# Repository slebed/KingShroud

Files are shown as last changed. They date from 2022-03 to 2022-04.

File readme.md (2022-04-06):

---
title: S. Lebed's RAT RIG Mods Page
---

> Created by: [Stephen Lebed](https://github.com/slebed)

## Description
Welcome to my Rat Rig Mods page.

## My Setup
I've designed all these mod around my Rat Rig V-Core3.  Its a custom size at 400x by 400y by 500z.  My toolhead is an EVA2.4 with a BondTech LGX, Mosquito Magnum and a CHT nozzle.

I have no plans to enclose my printer at this time and I don't even have an electronics panel.  All my electronic components are mounted on DIN rails.  I used the Rat Rig designed Y endstop block to secure the DIN rails to the 3030 extrusions allowing my to adjust the rails up or down as needed.

## My Stuff
Here are the links to my mods...   

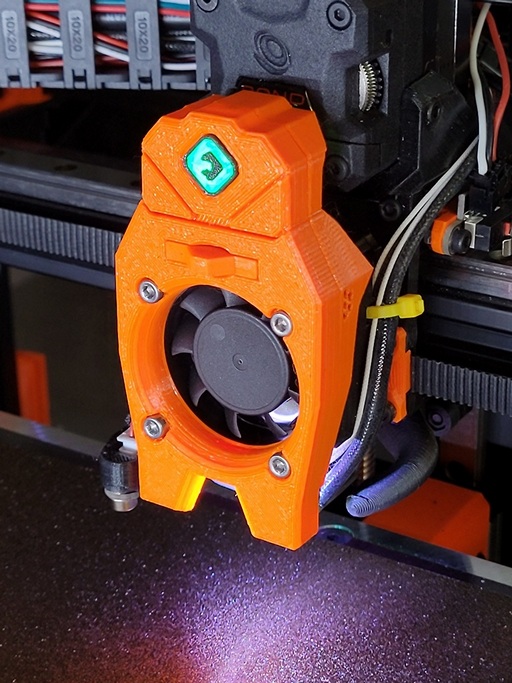
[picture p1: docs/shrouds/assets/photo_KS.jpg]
Stephen's King Shroud


[Click here for the Kings Shroud information and build instructions.](docs/shrouds/kings_shroud.md)

[Click here for my Auto Z offset information and build instructions.](docs/autoZ/autoZ.md)

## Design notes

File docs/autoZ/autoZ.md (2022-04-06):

---
title: S. Lebed's Auto Z offset Calibration
---
[Back to Index Page](../../readme.md)

> Created by: [Stephen Lebed](https://github.com/slebed)

S. Lebed's Auto Z offset Calibration

## Description
This is mod I designed for the Rat Rig V-Core3 3D Printer.  Inspired by the Voron auto Z offset calibration created by [Protoloft and can be found here.](https://github.com/protoloft/klipper_z_calibration)

#### Disclaimer
The names Voron, Stealthburner, EVA and Queen shroud are owned by their respective parties.  This design is under the same license as EVA 2.4 which is [CC BY-SA 4.0 license](https://creativecommons.org/licenses/by-sa/4.0/).

> **Warning:** This is a BETA release!  The stl files are getting updated often.  Please refer to the changelog.  These instructions may not be complete!

If you want to contact me I'm **slebed#1717** on the [Unofficial Rat Rig Discord Server](https://discord.gg/hEQhKNxN)

#### Attributions
This wouldn't have been possible without the amazing work done by the team at Rat Rig, Protoloft, Klipper and others.

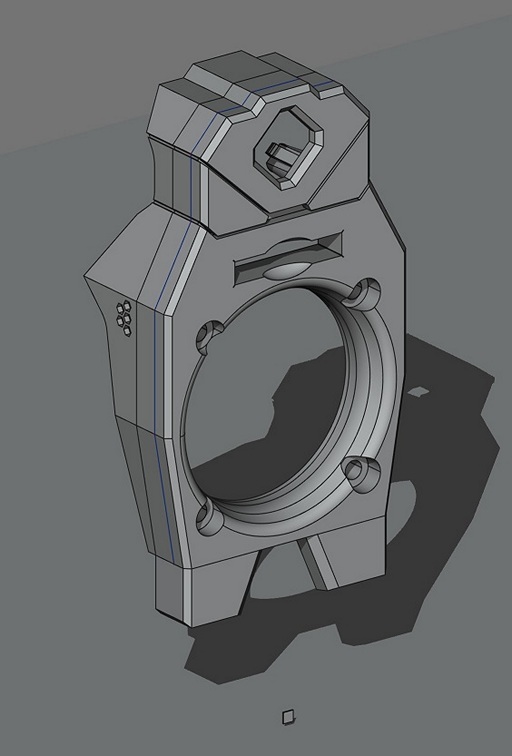
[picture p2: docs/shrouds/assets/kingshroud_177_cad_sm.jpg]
Stephen's King Shroud


## BOM

| No | Qty | Name | Printable | Notes|
| -- | --- | --- | --- |---|
| 1  | 1 | AutoZ Front Left Bedplate Endstop | [Yes](stl/KingsShroud_v179_body.stl)|
| 2  | 1 | AutoZ Rear Left Bedplate cable holder and flex plate guide | [Yes](stl/KingsShroud_v179_back.stl)||
| 3  | 1 | AutoZ Rear Right Bedplate flex plate guide | [Yes](stl/KingsShroud_v174-LogoLEDHolderLEDholder.stl)||
| 4  | 3 |Neopixel LED (ws2812)|No|I used these from [Amazon.com](https://www.amazon.com/dp/B00P2GQUYC/ref=cm_sw_em_r_mt_dp_PMNZGTJADRJEV3NSN1C2?_encoding=UTF8&psc=1) but any compatible ones should work.|
| 5  | 3 | 24awg stranded wire |No |I used this from [Amazon.ca](https://www.amazon.ca/dp/B07THYKBBK/ref=cm_sw_em_r_mt_dp_ZGJWJ1PHSKGGRQ51FVXV?_encoding=UTF8&psc=1)  |
| 6 | 2 | M2 or M2.5 x20mm Caphead screws 	 | No  ||
| 7 | 2 | M2 and M2.5 washers and nuts 	| No  ||

## Compatibility

This was designed around a stock V-Core 3 400, EVA 2.4 toolhead, and Euclid Probe

## Print preparation

Print the KingsShroud_v176.stl face down on the bed in your primary color.  Note that these parts were designed to be printed with PETG and are a tight fit.  If printing in ABS, please adjust for shrinkage.

I used SuperSlicer to print my parts using the following settings
 - 0.4 nozzle
 - 4 perimeters
 - 5 top and bottom layers
 - No supports are necessary
 - Bottom infill set to Archimedean Chords

 Wait!? What's that infill all about?  And what's going on with this...

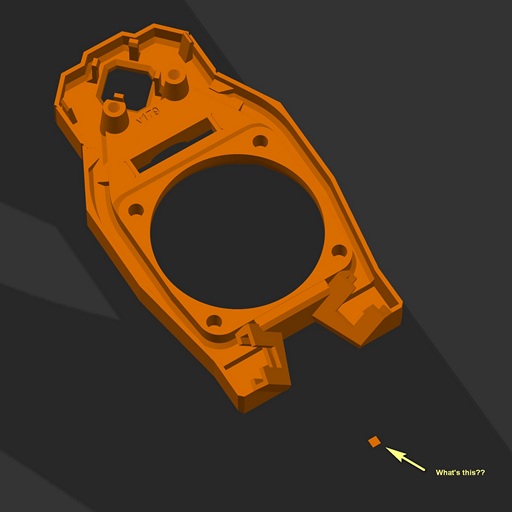
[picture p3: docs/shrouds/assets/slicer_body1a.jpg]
Stephen's King Shroud
 

Well its a small detail, but if print the body by itself and you set infill to this...

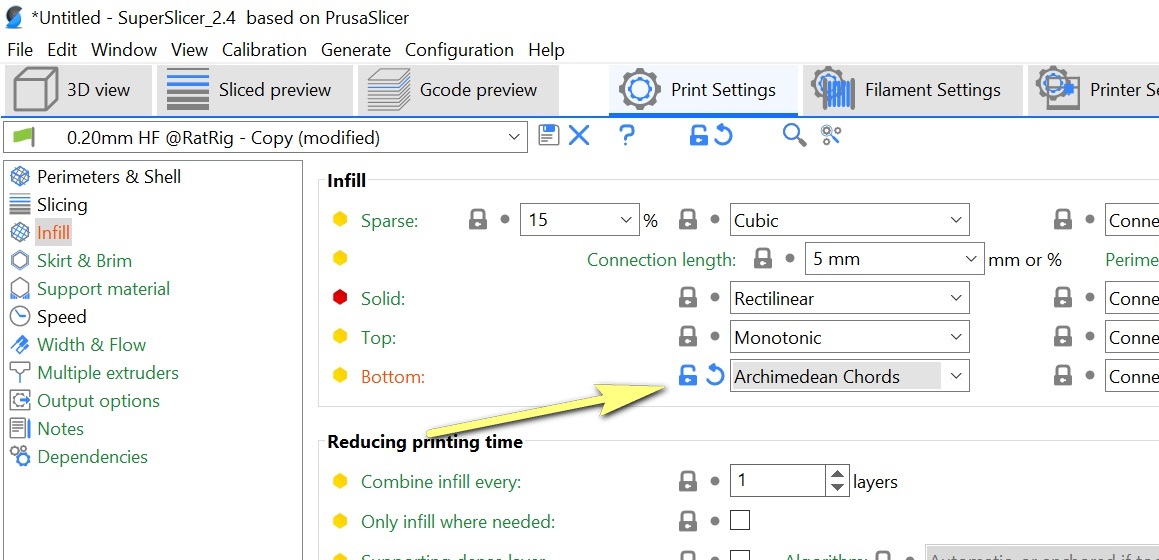
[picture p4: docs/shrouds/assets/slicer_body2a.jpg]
Stephen's King Shroud
  

Then the slicer will create this...

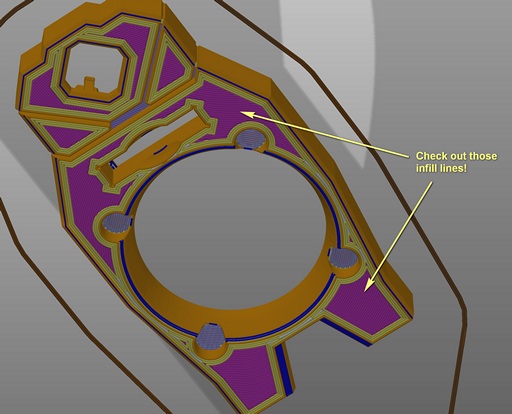
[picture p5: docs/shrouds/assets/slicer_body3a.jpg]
Stephen's King Shroud
 

 All the infill will radiate outward from the fan opening.

 Granted, its a detail that probably won't show if you print on a textured sheet or have a lot of squish, but its there.

> **Note:** The are four 'Pokey Poke' holes that will need to be drilled out prior to assembly.

Here is a image showing how the parts should be oriented in your slicer.

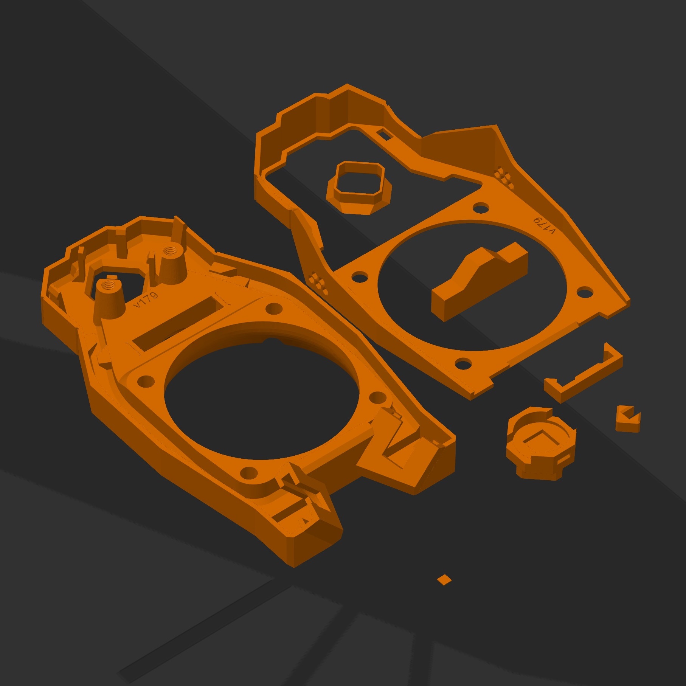
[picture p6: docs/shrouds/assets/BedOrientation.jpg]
Stephen's King Shroud
 

## Assembly instructions

#### Assembling the Logo LED Holder

Here are the printed parts for the Logo LED Holder.

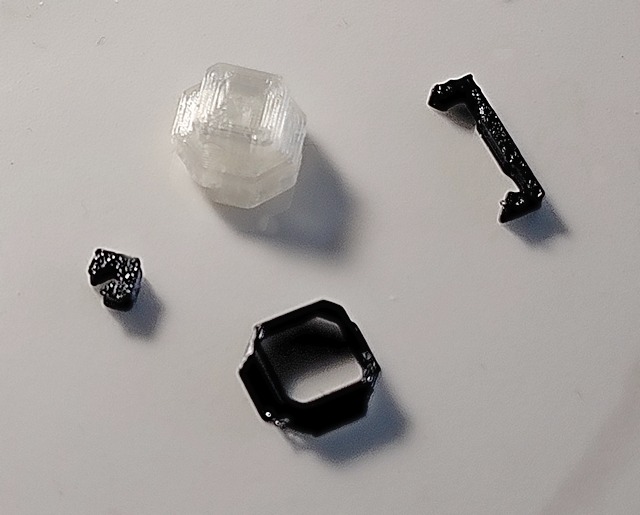
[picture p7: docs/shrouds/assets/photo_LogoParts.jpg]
Stephen's King Shroud
  

 - Press the EVA logo insert into the EVA Logo LED holder as shown in yellow below.

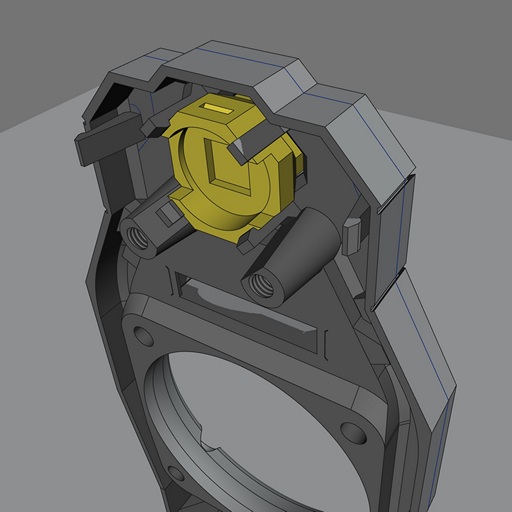
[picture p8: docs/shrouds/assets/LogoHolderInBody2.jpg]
Stephen's King Shroud
 

 - Press the EVA logo sheath onto the EVA logo LED holder as shown in yellow below.

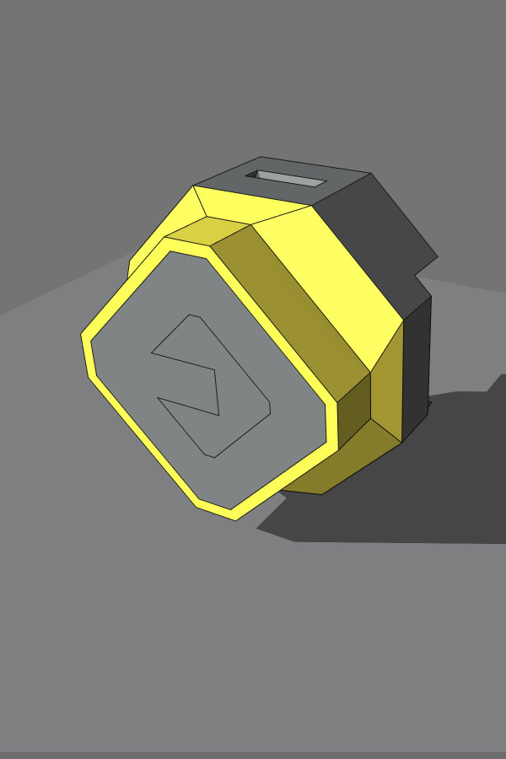
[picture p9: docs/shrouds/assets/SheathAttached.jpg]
Stephen's King Shroud
    

    Example of the assembled LogoLEDHolder

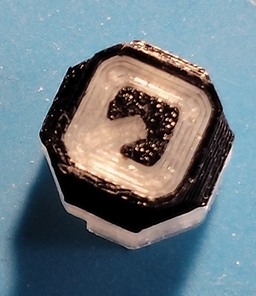
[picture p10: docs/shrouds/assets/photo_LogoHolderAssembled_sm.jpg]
Stephen's King Shroud
     

 - Press the EVA logo LED holder into the back of the King Shroud body as shown in yellow below.  The part should press fit into the opening in the body.

 > **Note:** Make sure the logo holder is oriented like the image below.  From the front the logo should be oriented like the photo above.

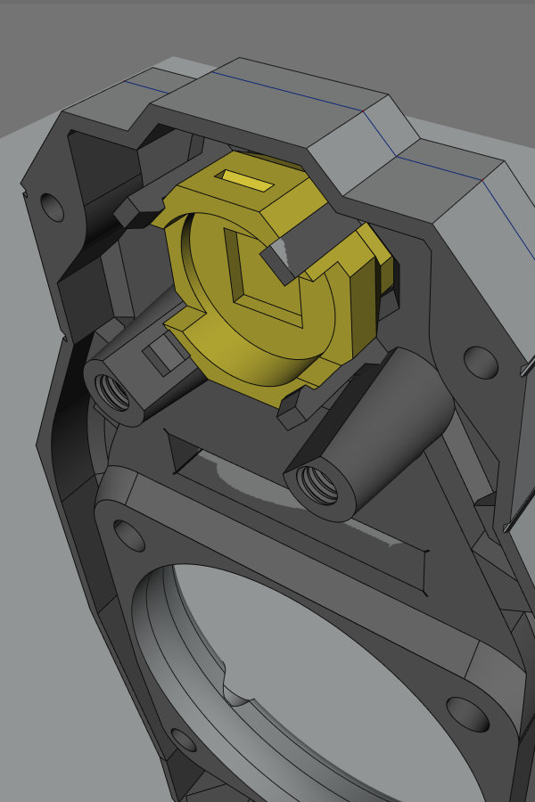
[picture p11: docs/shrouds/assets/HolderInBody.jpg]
Stephen's King Shroud
    

#### Wiring the Neopixel (ws2812) LED harness

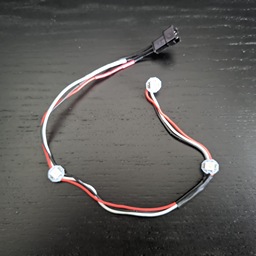
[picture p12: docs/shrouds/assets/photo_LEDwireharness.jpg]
Stephen's King Shroud
 

I used 28awg stranded wire cut to the following lengths: 3x 100mm long, 3x 60mm long, and 3x as long as you need to go from the first LED in line to a connector outside the King Shroud, at least 60mm.

- Solder the wires from the outside three pin connector to the 'IN' pins on the first LED.
- Solder the three 100mm wires from the 'OUT' of the first LED to the 'IN' of the second LED.
- Solder the three 60mm wires from the 'OUT' of the second LED so they all are laying over the three wires going 'IN'.
- Solder the other ends of the three 60mm wires to the 'IN' of the last LED.  

#### Inserting the LEDs into the King shroud

 - Starting with the last LED, insert it into the bottom right side of the King Shroud with the wires pointing out.  Slide the LED disk into the channel making sure the square housing of the LED should fits nicely into the slot.  The square LED housing should slide all the way into the channel.  A small nub will keep the LED from falling out.

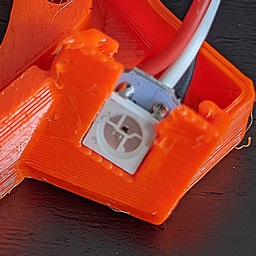
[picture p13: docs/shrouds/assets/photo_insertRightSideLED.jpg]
Stephen's King Shroud


- Insert the next LED into the left side bottom.  Make sure the LED is oriented so that all the wires are sticking out from the body.  Carefully press the LED completely into the holder for it.

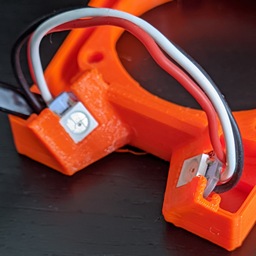
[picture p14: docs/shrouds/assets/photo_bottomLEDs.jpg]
Stephen's King Shroud


- Using a small flathead screwdriver or Allen wrench, careful push the wires into the channels as shown below.

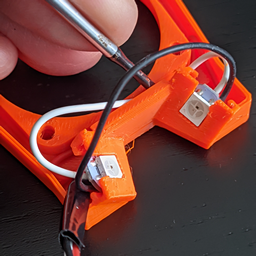
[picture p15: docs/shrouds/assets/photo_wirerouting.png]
Stephen's King Shroud
 
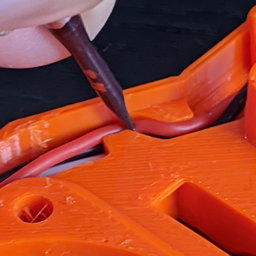
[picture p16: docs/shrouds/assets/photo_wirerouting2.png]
Stephen's King Shroud
 

- Place the remaining LED into the Logo LED Holder.  Its wires should lay across in the small slot.

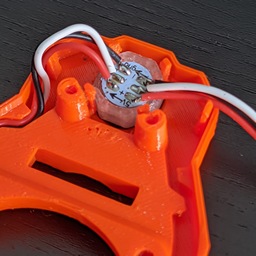
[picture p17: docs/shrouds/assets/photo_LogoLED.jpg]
Stephen's King Shroud
 

-  Press the clip over the LED so that it clicks into place.  Here is a photo showing the wiring and clip in place.

 Stephen's King Shroud
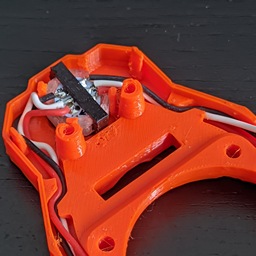
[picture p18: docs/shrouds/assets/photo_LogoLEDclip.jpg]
Stephen's King Shroud
 

#### Wiring the adxl345

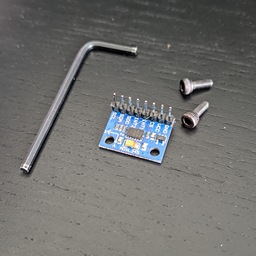
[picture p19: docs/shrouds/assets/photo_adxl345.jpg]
Stephen's King Shroud
 

Your ADXL345 will need to have its connector pin soldered in place.  Insert the pin on the side with the components and solder them in place from behind.  Attach the ADXL345 using the two 8mm M3 screws.  Carefully screw them into the threaded holes until they are tight.

Here is an example of the accelerometer mounted in place.

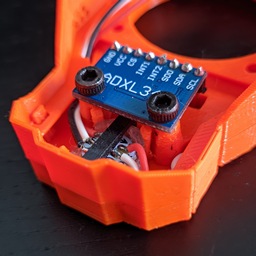
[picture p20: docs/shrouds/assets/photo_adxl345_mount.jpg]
Stephen's King Shroud
 

#### Attaching the back wire cover

Take the wires that go to the connector and pass them through the opening in the back cover.

 > **Note:** The ADXL345 board has been removed for clarity but can be left in place for this next step.

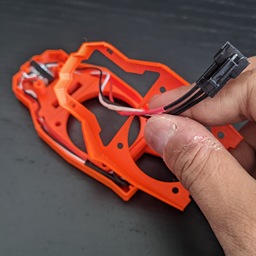
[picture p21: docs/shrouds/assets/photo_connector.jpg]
Stephen's King Shroud
 

Take the back cover and carefully lay it on the body.  There is a small grooved slot at the bottom that goes behind a tab above the bottom LED holders.  

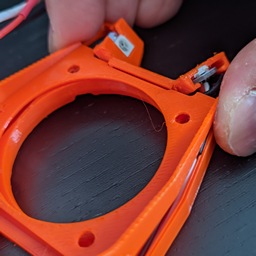
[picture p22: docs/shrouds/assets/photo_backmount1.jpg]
Stephen's King Shroud
 

Align the two upper tabs with the matching holes in the back and snap them into place.  They are circled in the photo below.

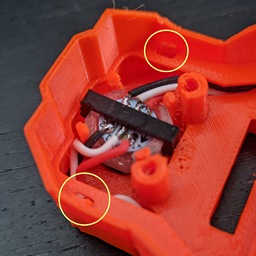
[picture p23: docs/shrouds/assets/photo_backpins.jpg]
Stephen's King Shroud
  

Take the four M3 x 20mm screws and pass them through the front of the body.  Attach the toolhead fan to the four screws.  Place the entire assembly to your EVA carriage and attach it like you would any other shroud.

**Photo below is the completed assembly on a Rat Rig V-Core3 with a Bondtech LGX and Mosquito Magnum, and Euclid probe.**

  Stephen's King Shroud

## Klipper Macros

  My LEDs are driven by a BTT Octopus 1.1 board and I'm using the RGBLED port.  If you are using a different board or a different port, then make sure you change 'pin:' to whatever pin you're using.

  I'm controlling the LEDs with these simple macros in Klipper.  They can be copy/pasted into your printer.cfg below the Macros section.

  ```
[neopixel board_rgb]
  pin: PB0
  chain_count: 3
  color_order: GRB
  initial_RED: 0
  initial_GREEN: 0
  initial_BLUE: 0

[gcode_macro TOOLHEAD_LOGOBLUE]
gcode:
  SET_LED LED=board_rgb RED=0 GREEN=0 BLUE=.2 INDEX=1 TRANSMIT=1

[gcode_macro TOOLHEAD_LOGORED]
gcode:
  SET_LED LED=board_rgb RED=0.1 GREEN=0 BLUE=0 INDEX=1 TRANSMIT=1

[gcode_macro TOOLHEAD_LOGOGREEN]
gcode:
  SET_LED LED=board_rgb RED=0 GREEN=0.1 BLUE=0 INDEX=1 TRANSMIT=1

[gcode_macro TOOLHEAD_LOGOWHITE]
gcode:
  SET_LED LED=board_rgb RED=1.0 GREEN=1.0 BLUE=1.0 INDEX=1 TRANSMIT=1

[gcode_macro TOOLHEAD_WORKLIGHT_FULL]
gcode:
  SET_LED LED=board_rgb RED=1.0 GREEN=1.0 BLUE=1.0 INDEX=2 TRANSMIT=0
  SET_LED LED=board_rgb RED=1.0 GREEN=1.0 BLUE=1.0 INDEX=3 TRANSMIT=1

[gcode_macro TOOLHEAD_WORKLIGHT_MED]
gcode:
  SET_LED LED=board_rgb RED=0.5 GREEN=0.5 BLUE=0.5 INDEX=2 TRANSMIT=0
  SET_LED LED=board_rgb RED=0.5 GREEN=0.5 BLUE=0.5 INDEX=3 TRANSMIT=1

[gcode_macro TOOLHEAD_WORKLIGHT_LOW]
gcode:
  SET_LED LED=board_rgb RED=0.25 GREEN=0.25 BLUE=0.25 INDEX=2 TRANSMIT=0
  SET_LED LED=board_rgb RED=0.25 GREEN=0.25 BLUE=0.25 INDEX=3 TRANSMIT=1
```

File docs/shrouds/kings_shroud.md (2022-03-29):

---
title: Stephen's King Shroud
---

> Created by: [Stephen Lebed](https://github.com/slebed)

Stephen's King Shroud

## Description
This is custom EVA shroud inspired by the Voron Stealthburner and Paweł Kucmus's EVA Queen shroud and carriage platform. This shroud should be a drop-in replacement for any EVA 2.4 shroud. Features of this shroud include a hidden ADXL345 mount, dual Neopixel RGB LEDs for seeing what you're printing and a Neopixel RGB LED backlit EVA logo.

Because of all the wires this shroud requires, I've designed channels for the wires to fit into which will hide them from view.  The channel should have enough room for three 24awg wires, although I recommend using 28awg wires due to their flexibility.

The dual Neopixel LEDs at the bottom are mounted at an angle away and downward to better illuminate the part being printed.  This also keeps the LEDs from shining in your face.  

There is a back cover that will snap into place to seal the wires in.  There is a small opening for the wires to go out to a connector.  

#### Disclaimer
The names Voron, Stealthburner, EVA and Queen shroud are owned by their respective parties.  This design is under the same license as EVA 2.4 which is [CC BY-SA 4.0 license](https://creativecommons.org/licenses/by-sa/4.0/).

> **Warning:** This is a BETA release!  The stl files are getting updated often.  Please refer to the changelog.  These instructions are not complete!

If you want to contact me I'm **slebed#1717** on the [Unofficial Rat Rig Discord Server](https://discord.gg/hEQhKNxN)

#### Attributions
This wouldn't have been possible without the amazing work done by Paweł Kucmus and his [EVA Carriage Standard](https://main.eva-3d.page/).  Please consider donating to his [Paypal.me](https://www.paypal.me/pkucmus).

Stephen's King Shroud

## BOM

| No | Qty | Name | Printable | Notes|
| -- | --- | --- | --- |---|
| 1a  | 1 | King Shroud body for most ADXL345 boards (15.5mm holes) | [Yes](stl/KingsShroud_v179_body.stl) |Print in primary color|
| 1b | 1 | King Shroud body for Adafruit ADXL345 boards (18.9mm holes) | [Yes](stl/KingsShroud_v181_Adafruit_v01.stl) |Print in primary color|
| 2  | 1 | King Shroud back cover | [Yes](stl/KingsShroud_v179_back.stl)|Print in primary color|
| 3  | 1 | EVA Logo LED holder | [Yes](stl/KingsShroud_v174-LogoLEDHolderLEDholder.stl)|Print in translucent or natural filament|
| 4  | 1 | EVA Logo LED clip | [Yes](stl/KingsShroud_v174-LogoLEDHolderLEDclip.stl)|Print in any color|
| 5  | 1 | EVA Logo sheath | [Yes](stl/KingsShroud_v166-LogoLEDHolderLogoLEDHolderSheath.stl)|Print in black filament|
| 6  | 1 | EVA Logo insert | [Yes](stl/KingsShroud_v167-LogoLEDHolderLogoInsert.stl)|Print in black filament|
| 7  | 1 | King Shroud ADXL port cover | [Yes](stl/KingsShroud_ADXL_cover_v04.STL)|
| 8  | 1 | ADXL345 | No  |I used this one from [Amazon.com](https://www.amazon.com/dp/B08HLP1MPY/ref=cm_sw_em_r_mt_dp_ZATE89GFDS2K0VEVVJN0?_encoding=UTF8&psc=1)|
| 9  | 3 |Neopixel LED (ws2812)|No|I used these from [Amazon.com](https://www.amazon.com/dp/B00P2GQUYC/ref=cm_sw_em_r_mt_dp_PMNZGTJADRJEV3NSN1C2?_encoding=UTF8&psc=1) but any compatible ones should work.|
| 10  | 3 | 28awg stranded wire |No |I used this from [Amazon.ca](https://www.amazon.ca/dp/B07THYKBBK/ref=cm_sw_em_r_mt_dp_ZGJWJ1PHSKGGRQ51FVXV?_encoding=UTF8&psc=1)  |
| 11 | 4 | M3 x20mm Caphead screw 	 | No  ||
| 12 | 2 | M3 x8mm Caphead screw 	| No  |Used for attaching ADXL to body

## Compatible EVA version

2.4 and newer.

## Print preparation

Print the KingsShroud_v176.stl face down on the bed in your primary color.  Note that these parts were designed to be printed with PETG and are a tight fit.  If printing in ABS, please adjust for shrinkage.

I used SuperSlicer to print my parts using the following settings
 - 0.4 nozzle
 - 4 perimeters
 - 5 top and bottom layers
 - No supports are necessary
 - Bottom infill set to Archimedean Chords

 Wait!? What's that infill all about?  And what's going on with this...

 Stephen's King Shroud

Well its a small detail, but if print the body by itself and you set infill to this...

  Stephen's King Shroud

Then the slicer will create this...

 Stephen's King Shroud

 All the infill will radiate outward from the fan opening.

 Granted, its a detail that probably won't show if you print on a textured sheet or have a lot of squish, but its there.

> **Note:** The are four 'Pokey Poke' holes that will need to be drilled out prior to assembly.

Here is a image showing how the parts should be oriented in your slicer.

 Stephen's King Shroud

## Assembly instructions

#### Assembling the Logo LED Holder

Here are the printed parts for the Logo LED Holder.

  Stephen's King Shroud

 - Press the EVA logo insert into the EVA Logo LED holder as shown in yellow below.

 Stephen's King Shroud

 - Press the EVA logo sheath onto the EVA logo LED holder as shown in yellow below.

    Stephen's King Shroud

    Example of the assembled LogoLEDHolder

     Stephen's King Shroud

 - Press the EVA logo LED holder into the back of the King Shroud body as shown in yellow below.  The part should press fit into the opening in the body.

 > **Note:** Make sure the logo holder is oriented like the image below.  From the front the logo should be oriented like the photo above.

    Stephen's King Shroud

#### Wiring the Neopixel (ws2812) LED harness

 Stephen's King Shroud

I used 28awg stranded wire cut to the following lengths: 3x 100mm long, 3x 60mm long, and 3x as long as you need to go from the first LED in line to a connector outside the King Shroud, at least 60mm.

- Solder the wires from the outside three pin connector to the 'IN' pins on the first LED.
- Solder the three 100mm wires from the 'OUT' of the first LED to the 'IN' of the second LED.
- Solder the three 60mm wires from the 'OUT' of the second LED so they all are laying over the three wires going 'IN'.
- Solder the other ends of the three 60mm wires to the 'IN' of the last LED.  

#### Inserting the LEDs into the King shroud

 - Starting with the last LED, insert it into the bottom right side of the King Shroud with the wires pointing out.  Slide the LED disk into the channel making sure the square housing of the LED should fits nicely into the slot.  The square LED housing should slide all the way into the channel.  A small nub will keep the LED from falling out.

Stephen's King Shroud

- Insert the next LED into the left side bottom.  Make sure the LED is oriented so that all the wires are sticking out from the body.  Carefully press the LED completely into the holder for it.

Stephen's King Shroud

- Using a small flathead screwdriver or Allen wrench, careful push the wires into the channels as shown below.

 Stephen's King Shroud
 Stephen's King Shroud

- Place the remaining LED into the Logo LED Holder.  Its wires should lay across in the small slot.

 Stephen's King Shroud

-  Press the clip over the LED so that it clicks into place.  Here is a photo showing the wiring and clip in place.

 Stephen's King Shroud
 Stephen's King Shroud

#### Wiring the adxl345

 Stephen's King Shroud

Your ADXL345 will need to have its connector pin soldered in place.  Insert the pin on the side with the components and solder them in place from behind.  Attach the ADXL345 using the two 8mm M3 screws.  Carefully screw them into the threaded holes until they are tight.

Here is an example of the accelerometer mounted in place.

 Stephen's King Shroud

#### Attaching the back wire cover

Take the wires that go to the connector and pass them through the opening in the back cover.

 > **Note:** The ADXL345 board has been removed for clarity but can be left in place for this next step.

 Stephen's King Shroud

Take the back cover and carefully lay it on the body.  There is a small grooved slot at the bottom that goes behind a tab above the bottom LED holders.  

 Stephen's King Shroud

Align the two upper tabs with the matching holes in the back and snap them into place.  They are circled in the photo below.

  Stephen's King Shroud

Take the four M3 x 20mm screws and pass them through the front of the body.  Attach the toolhead fan to the four screws.  Place the entire assembly to your EVA carriage and attach it like you would any other shroud.

**Photo below is the completed assembly on a Rat Rig V-Core3 with a Bondtech LGX and Mosquito Magnum, and Euclid probe.**

  Stephen's King Shroud

## Klipper Macros

  My LEDs are driven by a BTT Octopus 1.1 board and I'm using the RGBLED port.  If you are using a different board or a different port, then make sure you change 'pin:' to whatever pin you're using.

  I'm controlling the LEDs with these simple macros in Klipper.  They can be copy/pasted into your printer.cfg below the Macros section.

  ```
[neopixel board_rgb]
  pin: PB0
  chain_count: 3
  color_order: GRB
  initial_RED: 0
  initial_GREEN: 0
  initial_BLUE: 0

[gcode_macro TOOLHEAD_LOGOBLUE]
gcode:
  SET_LED LED=board_rgb RED=0 GREEN=0 BLUE=.2 INDEX=1 TRANSMIT=1

[gcode_macro TOOLHEAD_LOGORED]
gcode:
  SET_LED LED=board_rgb RED=0.1 GREEN=0 BLUE=0 INDEX=1 TRANSMIT=1

[gcode_macro TOOLHEAD_LOGOGREEN]
gcode:
  SET_LED LED=board_rgb RED=0 GREEN=0.1 BLUE=0 INDEX=1 TRANSMIT=1

[gcode_macro TOOLHEAD_LOGOWHITE]
gcode:
  SET_LED LED=board_rgb RED=1.0 GREEN=1.0 BLUE=1.0 INDEX=1 TRANSMIT=1

[gcode_macro TOOLHEAD_WORKLIGHT_FULL]
gcode:
  SET_LED LED=board_rgb RED=1.0 GREEN=1.0 BLUE=1.0 INDEX=2 TRANSMIT=0
  SET_LED LED=board_rgb RED=1.0 GREEN=1.0 BLUE=1.0 INDEX=3 TRANSMIT=1

[gcode_macro TOOLHEAD_WORKLIGHT_MED]
gcode:
  SET_LED LED=board_rgb RED=0.5 GREEN=0.5 BLUE=0.5 INDEX=2 TRANSMIT=0
  SET_LED LED=board_rgb RED=0.5 GREEN=0.5 BLUE=0.5 INDEX=3 TRANSMIT=1

[gcode_macro TOOLHEAD_WORKLIGHT_LOW]
gcode:
  SET_LED LED=board_rgb RED=0.25 GREEN=0.25 BLUE=0.25 INDEX=2 TRANSMIT=0
  SET_LED LED=board_rgb RED=0.25 GREEN=0.25 BLUE=0.25 INDEX=3 TRANSMIT=1
```

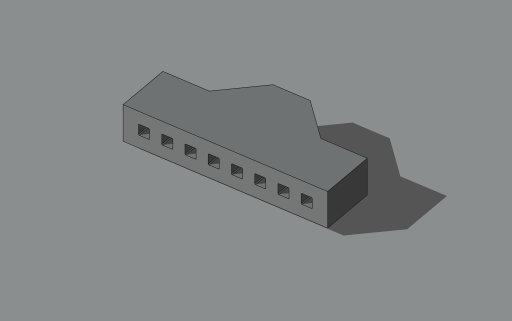
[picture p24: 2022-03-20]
docs/shrouds/assets/ADXL345cover.jpg

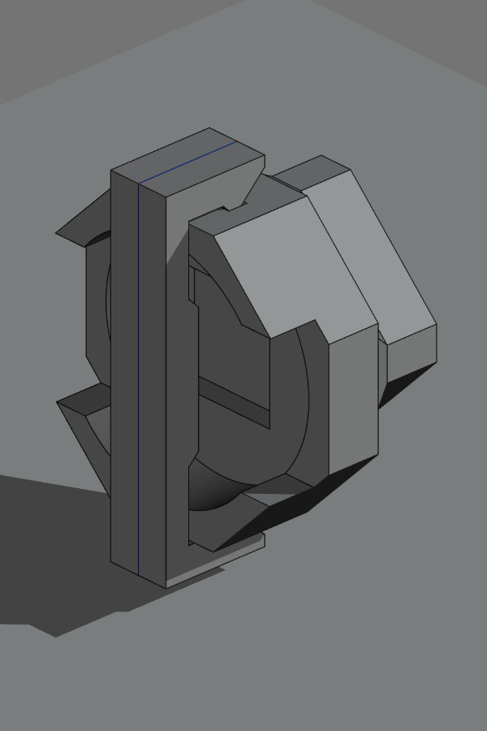
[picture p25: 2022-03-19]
docs/shrouds/assets/LEDHolderClipAttachExample_177.jpg

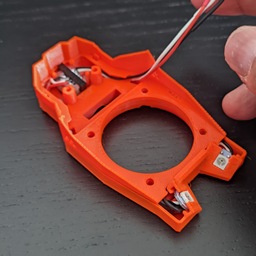
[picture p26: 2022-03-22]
docs/shrouds/assets/photo_connectorroute.jpg

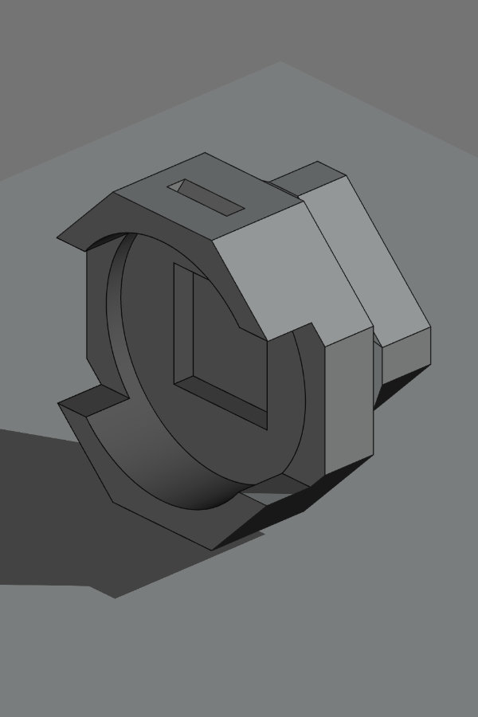
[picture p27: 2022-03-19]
docs/shrouds/assets/LEDHolder_177.jpg

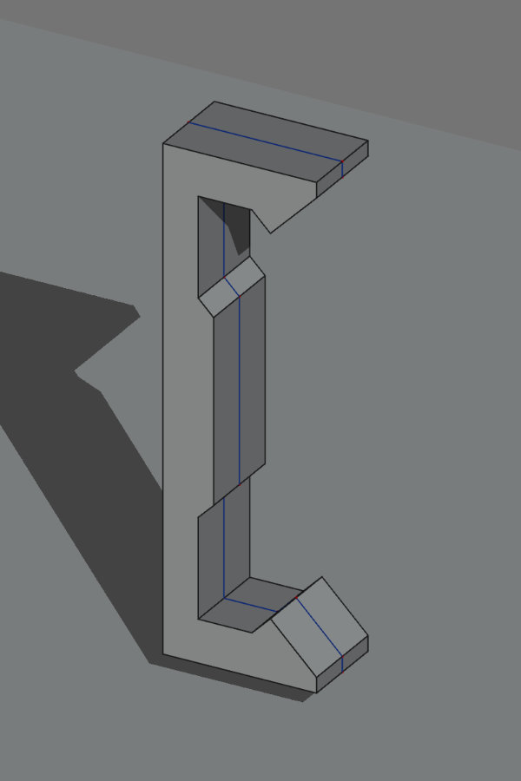
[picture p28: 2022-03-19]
docs/shrouds/assets/LEDHolderClip_177.jpg

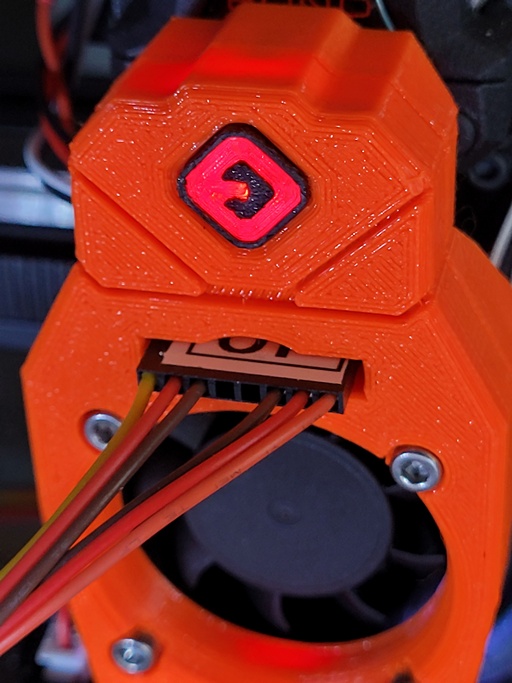
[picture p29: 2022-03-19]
docs/shrouds/assets/photo_KS_ADXLwired.jpg

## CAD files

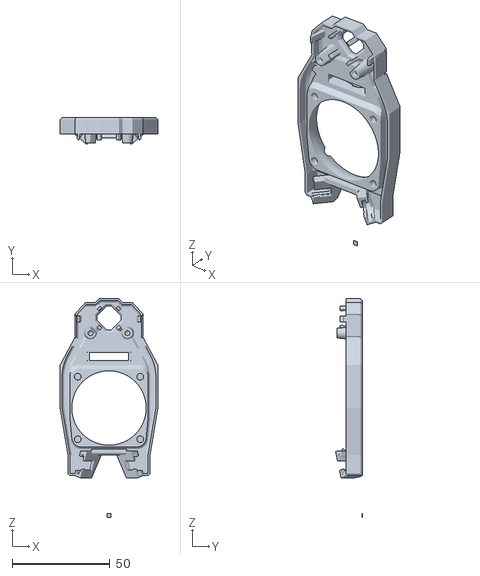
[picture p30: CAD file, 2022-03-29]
docs/shrouds/stl/KingsShroud_v181_Adafruit_v01.stl
50.0 x 13.7 x 112.0

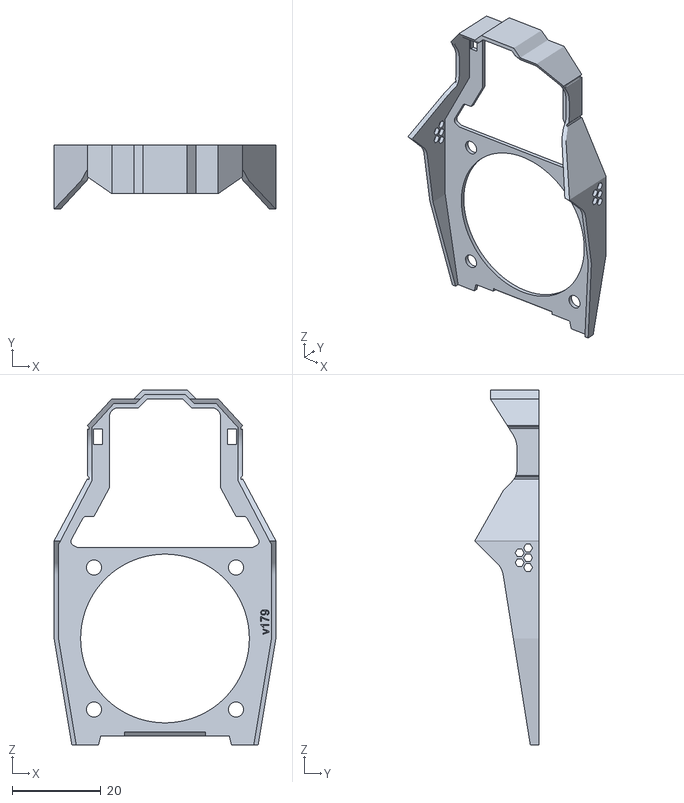
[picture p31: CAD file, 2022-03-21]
docs/shrouds/stl/KingsShroud_v179_back.stl
50.0 x 14.5 x 80.0

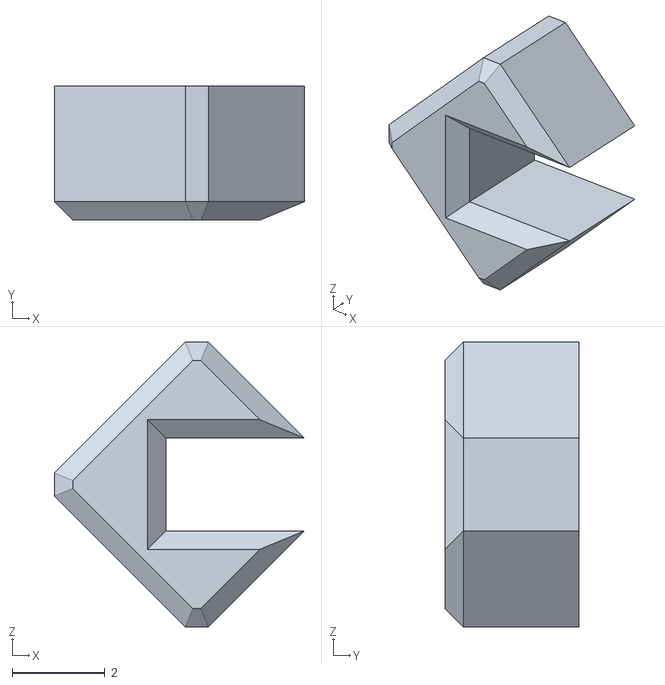
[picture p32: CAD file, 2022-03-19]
docs/shrouds/stl/KingsShroud_v167-LogoLEDHolderLogoInsert.stl
5.41 x 2.90 x 6.16

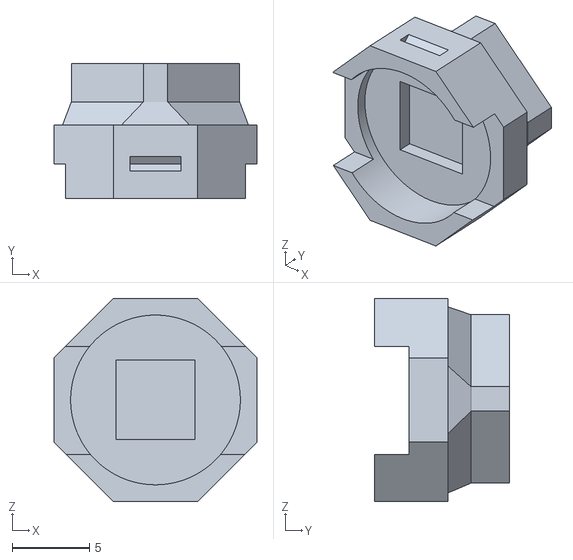
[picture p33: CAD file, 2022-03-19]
docs/shrouds/stl/KingsShroud_v174-LogoLEDHolderLEDholder.stl
13.2 x 8.75 x 13.2

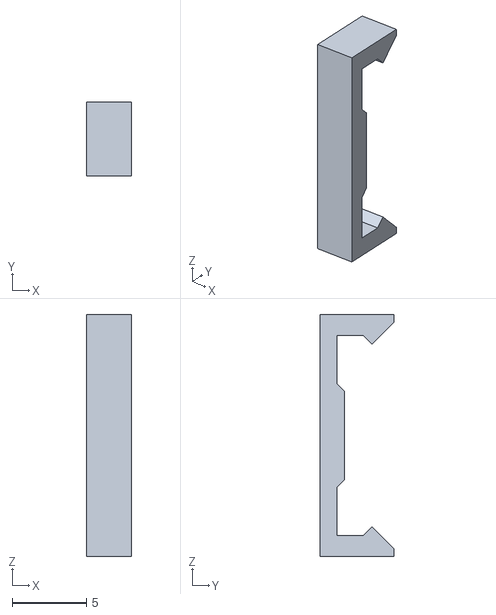
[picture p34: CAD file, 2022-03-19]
docs/shrouds/stl/KingsShroud_v174-LogoLEDHolderLEDclip.stl
3.00 x 5.00 x 16.3

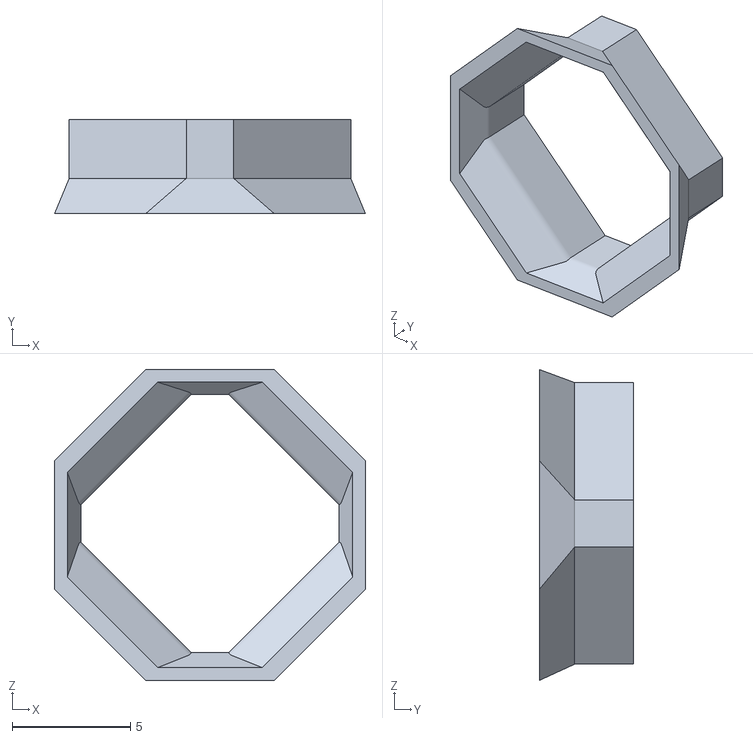
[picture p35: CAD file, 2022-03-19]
docs/shrouds/stl/KingsShroud_v166-LogoLEDHolderLogoLEDHolderSheath.stl
13.2 x 4.00 x 13.2

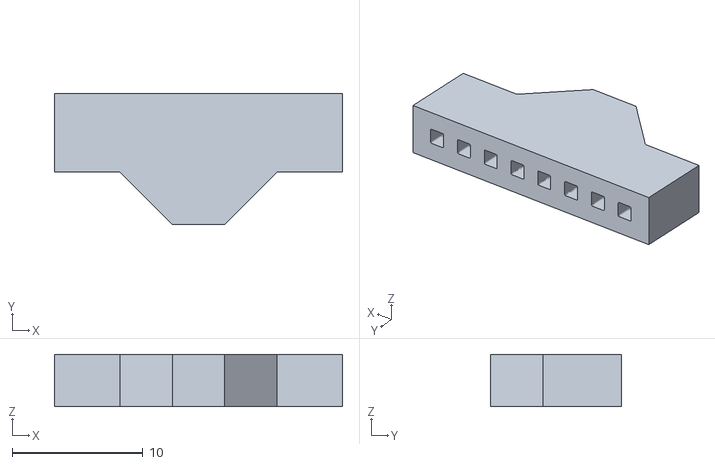
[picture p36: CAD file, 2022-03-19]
docs/shrouds/stl/KingsShroud_ADXL_cover_v04.STL
22.0 x 10.0 x 4.00

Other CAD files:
docs/shrouds/stl/KingsShroud_v179_body.stl
docs/shrouds/stl/KingsShroud_v176-back.stl
docs/shrouds/stl/older_versions/KingsShroud_v176-back.stl
docs/shrouds/stl/older_versions/KingsShroud_v176_body.stl
docs/shrouds/stl/KingsShroud_v176_body.stl

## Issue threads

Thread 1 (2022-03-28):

Adafruit ADXL

nicedevil007, 2022-03-28:
Hey slebed, first I want to thank you realy much for this awesome design!

I just wanted to modify the file to allow my genuine Adafruit ADXL sensor to be mounted but can't because of not provided step files, I hope you can do an alternate version for us "Adafruit" users as well?

The hole spacing is 18.9mm.

https://www.amazon.com/Adafruit-ADXL345-Triple-Axis-Accelerometer-ADA1231/dp/B01BT4N9BC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

slebed, 2022-03-28:
Thanks for the kind words and I'll try to get you a new version tonight.

Best,
Stephen

On Mon., Mar. 28, 2022, 1:25 p.m. nicedevil007, ***@***.***>
wrote:

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

slebed, 2022-03-29:
I've updated and posted a new body .STL with 18.9mm spacing

Closed 2022-03-29.

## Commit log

2022-03-19 test
    test
    [ADXL_cover_v01.FCStd, ADXL_cover_v01.STL, ADXL_cover_v02.FCStd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]
2022-03-20 moved shrouds folder into docs
    [KingsShroud_v166-ADXL345_cover.stl, KingsShroud_v166-LogoLEDHolderLogoLEDHolderSheath.stl, KingsShroud_v167-LogoLEDHolderLogoInsert.stl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]
2022-03-20 Added adxl cover
    [KingsShroud_ADXL_cover_v04.STL]
2022-03-21 Updated stl files
    [KingsShroud_v176-back.stl, KingsShroud_v176_body.stl, KingsShroud_v179_back.stl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]
2022-03-22 Update links to stl files
2022-03-22 Adding instructions for klipper macros
2022-03-22 Added bed orientation
2022-03-29 Added a new stl for Adafruit ADXL345 boards
    [KingsShroud_v181_Adafruit_v01.stl]
